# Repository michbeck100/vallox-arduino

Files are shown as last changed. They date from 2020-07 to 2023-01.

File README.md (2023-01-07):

# vallox-esp
Control your Vallox ventilation system using an arduino.

## Introduction

This project extends the analog step switch VSS-P from Vallox, that is used to control a ventilation system like the [90 SC](http://www.vallox.com/files/412/KAHU90SC_D_280909.pdf).

It uses an arduino board with code to create a 10 bit DAC (Digital-Analog-Converter).

This way it's possible to create voltages between 0 and 10V, which controls how fast the fans of the ventilation system run. 

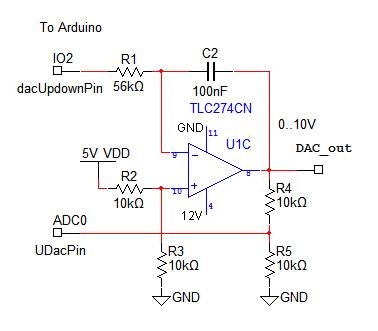
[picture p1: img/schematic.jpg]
Schematic


### Dependencies

The hardware consists of an Arduino Nano with an attached ENC28J60 ethernet shield, so the dependencies are as follows:

- [EthernetENC](https://github.com/JAndrassy/EthernetENC) for ENC28J60 support.
- [MQTT Client](https://pubsubclient.knolleary.net) to connect using mqtt.

The dependencies can be installed using the library manager in the Arduino IDE.

### Credits

This project is based on the [idea](http://www.hillier.de/lueftung.php) of Gernot Hillier.

For the arduino code of the 10 bit DAC see [here](http://www.avdweb.nl/arduino/hardware-interfacing/simple-10-bit-dac.html).

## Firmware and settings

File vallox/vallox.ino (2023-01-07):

#include <Arduino.h>
#include <SPI.h>
#include <EthernetENC.h>
#include <PubSubClient.h>

#include "Dac.h"

byte mac[] = {0xDE, 0xAD, 0xBE, 0xEF, 0xFE, 0xED};

// mqtt client
EthernetClient net;
PubSubClient mqttClient(net);

const char broker[] = "mqtt.nas.fritz.box";
int        port     = 1883;

const int dacUpdownPin = 7;
const int UDacPin = 0;
const int AnalogSwitchPin = 3;
Dac dac(dacUpdownPin, UDacPin);

char switchPosition = '?';

void setVentilation(int value) {
  Serial.print("Setting value to ");
  Serial.println(value);
  if (value < 560 || value > 1023) {
    Serial.println("Invalid value, must be between 560 and 1023");
    return;
  }
  dac.write(value);
}

char readAnalogSwitch() {
  int rawVal = analogRead(AnalogSwitchPin);
  if (rawVal > 286 && rawVal < 347)
    return 'A';
  if (rawVal > 704 && rawVal < 764)
    return '2';
  if (rawVal > 821 && rawVal < 882)
    return '3';
  if (rawVal > 993)
    return '4';
  return '?';
}

void callback(char* topic, byte* payload, unsigned int length) {
  char format[16];
  snprintf(format, sizeof format, "%%%ud", length);

  // Convert the payload
  int payload_value = 0;
  if (sscanf((const char *) payload, format, &payload_value) == 1)
    setVentilation(payload_value);
  else
    Serial.println("error converting payload to int");
}

void reconnect() {
  // Loop until we're reconnected
  while (!mqttClient.connected()) {
    Serial.print("Attempting MQTT connection...");
    // Attempt to connect
    if (mqttClient.connect("vallox-arduino")) {
      Serial.println("connected");
      mqttClient.subscribe("vallox/ventilation/set");
    } else {
      Serial.print("failed, rc=");
      Serial.print(mqttClient.state());
      Serial.println(" try again in 5 seconds");
      // Wait 5 seconds before retrying
      delay(5000);
    }
  }
}

void setup() {
  // initialize serial communication at 9600 bits per second:
  Serial.begin(9600);

  // connect to mqtt broker 
  mqttClient.setServer(broker, port);
  mqttClient.setCallback(callback);

  // start the Ethernet connection and the server:
  Ethernet.init(10);
  Ethernet.begin(mac);
  
  // Check for Ethernet hardware present
  if (Ethernet.hardwareStatus() == EthernetNoHardware) {
    Serial.println("Ethernet shield was not found.  Sorry, can't run without hardware. :(");
    while (true) {
      delay(1); // do nothing, no point running without Ethernet hardware
    }
  }

  Serial.print("ip address is ");
  Serial.println(Ethernet.localIP());

  setVentilation(700);
  switchPosition = readAnalogSwitch();
}

void loop() {
  static int counter = 0;
  char current;

  delay(100);

  if (!mqttClient.connected()) {
    reconnect();
  }
  mqttClient.loop();

  current = readAnalogSwitch();
  if (current != '?' && current != switchPosition) {
    switchPosition = current;
    if (current == '2') {
      setVentilation(560);
    } else if (current == '3') {
      setVentilation(700);
    } else if (current == '4') {
      setVentilation(1023);
    }
  }
  
  counter++;
  /* every 5 sec */
  if ( counter % 50 == 0) {
    //stabilize DAC output
    dac.refresh();

    // send message, the Print interface can be used to set the message contents
    char payload[16];
    itoa(dac.read(), payload, 10);
    mqttClient.publish("vallox/ventilation", payload);
  }

}

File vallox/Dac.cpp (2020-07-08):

/* 
Simple 10 bit DAC for the Arduino
Version 21-3-2013
1. changed constructor

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
write(): Write a value to the DAC. 0 = 0V, 1023 = 10V.
read():  Read the actual output voltage.
refresh(): Because of leakage current, refresh the DAC periodically (10 sec. for 1 LSB error).
The settling time is max. 20ms.
Don't touch C1 / R1 during run.

               C1 100nF 10% MKT  
                _____||____
               |     ||    |  
           R1  |  |\       | LMC6482
   I/O 2--56k-----|-\      |
                  |  \ ____|____ DAC out 0 ... 10V
           R2     |  /    |     
     5V- -10k-----|+/     |
               |  |/  R4 10k
               |          |_____
           R3 10k         |     |
               |      R5 10k    |
               |          |     |
              GND        GND    |
    ADC 0-----------------------
         
            5V |      _       _
               |     | |     | |
  I/O 2        |     | |     | |
          2.5V |_____| |_____| |______
               |
               |
            0V |______________________
          
               |______
               |      \_______
 DAC out       |              \_______ 
 (not to scale)| 
               |______________________
*/

#include <Arduino.h>
#include "Dac.h"

Dac::Dac(int dacUpdownPin, int UDacPin):
dacUpdownPin(dacUpdownPin), UDacPin(UDacPin), overshoot(5)
{ write(512); // set to 2,5V 
  write(512); // the first conversion can be wrong 
}

bool Dac::write(int val)
{ targetVal = val;
  if(targetVal > 1023) targetVal = 1023;
  if(targetVal < 0) targetVal = 0;   
  
  if(abs(read() - targetVal) > overshoot) // avoid overshoot from setDac() for small value changes
    if(!setDac()) return false; 
  if(!fineTune()) return false;
  if(abs(read() - targetVal) > 1) return false; // final error check
  return true;
} 

bool Dac::refresh()
{ if(!fineTune()) return false;
  return true;
} 

int Dac::read() const// not inline
{ return analogRead(UDacPin);
}

inline int Dac::fastRead() const
{ return analogRead(UDacPin);
}
  
/* To increase the DAC speed, the overshoot is reduced by an overshoot value (5). 
   However, this mechanism has a small influence on the accuracy. The DAC error is 0 or 1. 
   When the overshoot value is changed to 0 the DAC error is mostly 0. This mechanism can perhaps be improved.
*/

bool Dac::setDac()  
{ const byte timeout1 (255); // maxSettlingTime1 = 195
  int targetCorr; 

  if(read() == targetVal) return true; 
  if(read() < targetVal) 
  { targetCorr = targetVal - overshoot; // reduce overshoot caused by adc delay
    dacUp();
    for(settlingTime1=0; settlingTime1 < timeout1; settlingTime1++) 
    { if(fastRead() >= targetCorr) 
      { dacHold(); 
        break;
      }
    }
  } else  
  { targetCorr = targetVal + overshoot;
    dacDown();
    for(settlingTime1=0; settlingTime1 < timeout1; settlingTime1++)
    { if(fastRead() <= targetCorr)  
      { dacHold(); 
        break;
      }
    }
  }
  dacHold(); // end always with hold, in case of timeout
  if(settlingTime1 >= timeout1) return false;
  else return true;
}

bool Dac::fineTune() // produces no overshoot 
{ const byte timeout2 (80); // maxSettlingTime2 ~ 20
  const byte halfLsbCorrection (1);
  
  if(read() == targetVal) return true; // avoid ripple at refresh()
  if(read() < targetVal) 
  { for(settlingTime2=0; settlingTime2 < timeout2; settlingTime2++)
    { dacUp(); dacHold(); // finetuning with short pulse 
      if(fastRead() >= targetVal) 
      { for(int i=0; i<halfLsbCorrection; i++) dacUp(); // reduce error to 0
        break;
      }
    }     
  } else  
  { for(settlingTime2=0; settlingTime2 < timeout2; settlingTime2++)
    { dacDown(); dacHold(); // finetuning with short pulse 
      if(fastRead() <= targetVal) 
      { for(int i=0; i<halfLsbCorrection; i++) dacDown(); // reduce error to 0
        break;
      }
    }
  }
  dacHold(); // end always with hold, in case of timeout
  if(settlingTime2 >= timeout2) return false;
  else return true;
}

void Dac::dacUp() const
{ digitalWrite(dacUpdownPin, LOW);
  pinMode(dacUpdownPin, OUTPUT); 
}
void Dac::dacDown() const
{ digitalWrite(dacUpdownPin, HIGH);
  pinMode(dacUpdownPin, OUTPUT);
}

void Dac::dacHold() const
{ pinMode(dacUpdownPin, INPUT); // high impedance tristate 
  digitalWrite(dacUpdownPin, LOW); // disable pull up resistor 1*)
}

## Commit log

2016-09-19 Added fritzing model and updated README.md
    [circuit.fzz]
2018-09-27 add initial arduino code, changed fritzing sketch to arduino nano
2018-10-10 Move Arduino source to folder as requested by Arduino IDE
2020-07-08 Add 10-bit dac library from http://www.avdweb.nl/arduino/hardware-interfacing/simple-10-bit-dac.html as the original source doesn't exist anymore
    [Dac.cpp]
2020-07-08 Add schematic for 10 bit dac

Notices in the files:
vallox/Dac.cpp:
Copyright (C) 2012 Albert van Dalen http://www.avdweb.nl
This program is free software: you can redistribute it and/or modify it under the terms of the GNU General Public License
